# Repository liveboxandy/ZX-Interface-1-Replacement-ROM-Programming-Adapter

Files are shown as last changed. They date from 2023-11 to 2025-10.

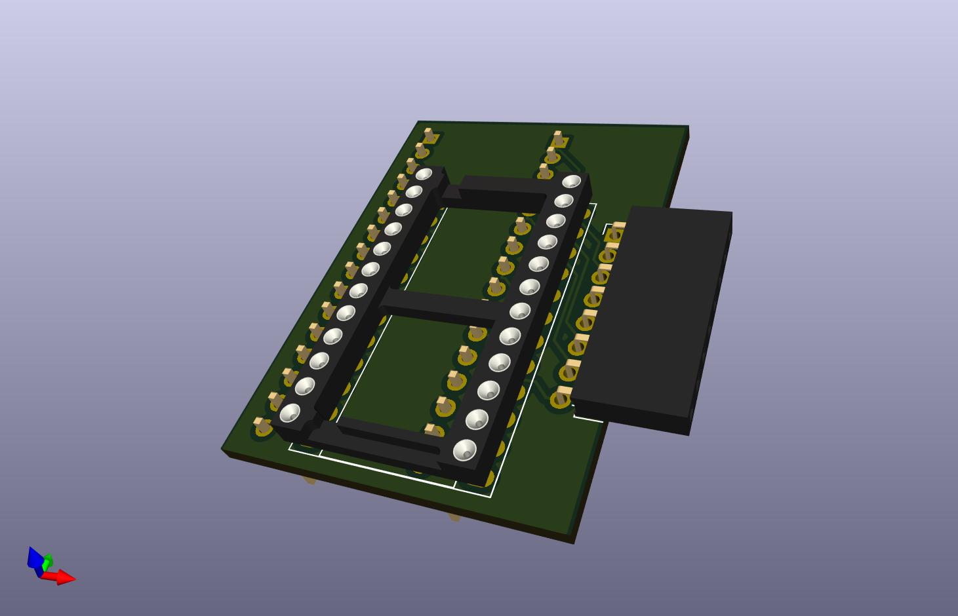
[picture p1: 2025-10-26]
ZX Interface 1 ROM Adapter.jpg

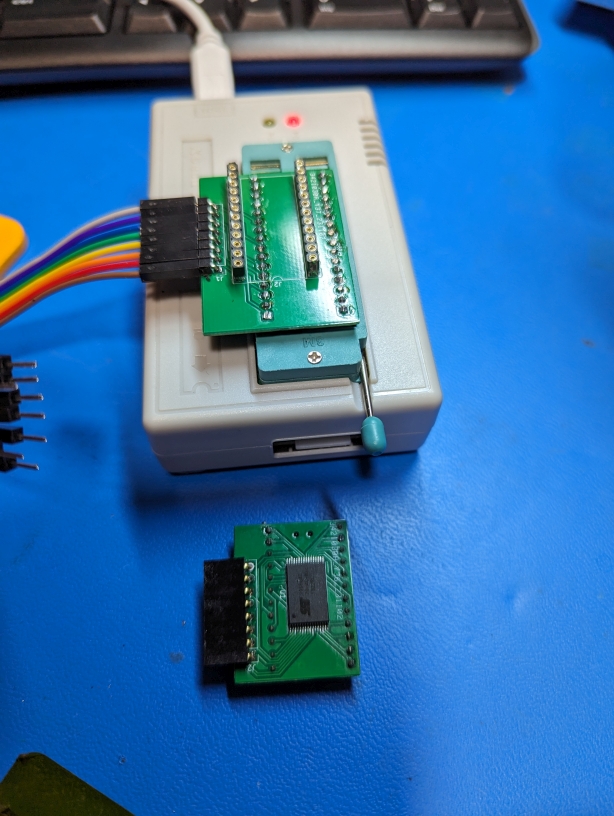
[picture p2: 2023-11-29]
Pictures/ROM Top.jpg

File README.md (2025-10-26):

# ZX-Interface-1-Replacement-ROM-Programming-Adapter
Programming adapter for the ZX Interface 1 Replacement ROM.

This is the programming adapter that is required to allow reprogramming of the ZX Interface 1 Replacement ROM.

You need to link J1 Pins 1-8 on the adapter PCB to J1 Pins 1-8 (1-1,2-2,3-3,4-4,5-5,6-6,7-7,8-8) on the ROM PCB and select the correct SST39SF device on the programmer. You do not need to connect the 9th pin on the replacement ROM. See the ROM folder for more information on layout of the ROM and where to place the ROM images.

It can also be used to reprogram the Retroleum 24-pin switchable ROM replacement module with a bit of faffing about. See the relevant picture in the pictures folder for connection details.

The Retroeleum ROM unused connector is wired as follows starting from the left pin.

A12, ~WE, A14, A13, ~CE

and is configured in the following manner,

A12 - connected to 24 Pin Socket Pin 21 and is left unconnected.

~WE pulled Hi by 10K resistor in normal operation. Can be overidden by programmer. Connect to Adapter J1 pin 1 to program.

A14 pulled Lo by 10K resistor in normal operation. Can be overidden by programmer. Connect to Adapter J1 Pin 6 to program.

A13 pulled Lo by 10K resistor in normal operation. Can be overidden by programmer. Connect to Adapter J1 Pin 7 to program. This can be used in the Interface 1 to allow the use of 16K ROM images. 

~CE pulled Lo by 10K resistor in normal operation. Can be overidden by programmer. Connect to Adapter J1 Pin 8 to program.

A15 selects ROM to use by the switch, pulls line Hi via 10K to 5V or Lo via short to Gnd. Can be manually switched when programming to allow different ROMs to be selected (8K images unless A13 will be connected in the IF1 when 16K images can be used).

A16 permanently connected to Ground. Cannot be overridden by programmer.

To program,

1 - Select the correct device SST39SF010 DIP32.

2 - Add wires for ~WE, A14, A13 and ~CE. See picture for details.

3 - Device ID 'should' work but programmer should complain with a Pin 2 connection error if Pin Detect is ON. Now turn OFF Pin Detect.

4 - Erase EEPROM.

5 - Set Switch to A.

6 - Load ROM A at offset 0x00000

7 - Program

8 - Set Switch to B.

9 - Load ROM B at offset 0x00000

10 - Program - Ensure that Erase before Programming is NOT selected.

You should now have two ROMs programmed and can be selected by the switch. 

If using 16K ROM images, connect A13 on the unused connector to address A13 on the Interface 1. This can be found on the Spectrum Edge Connector. See picture for details. 

Comments - Good Bad or indifferent on https://www.facebook.com/groups/zxspa/

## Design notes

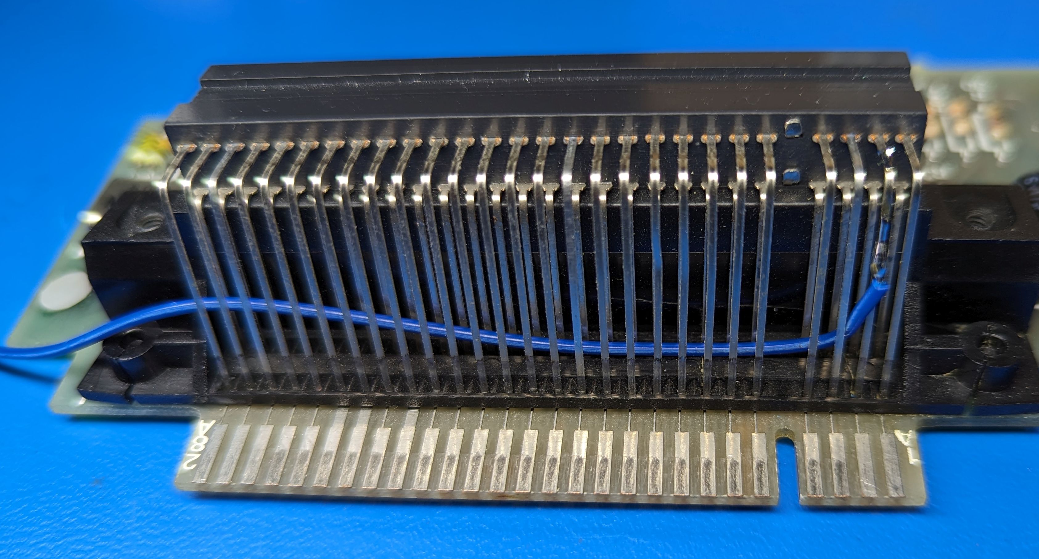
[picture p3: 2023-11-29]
Pictures/ZX Interface 1 A13 location.jpg

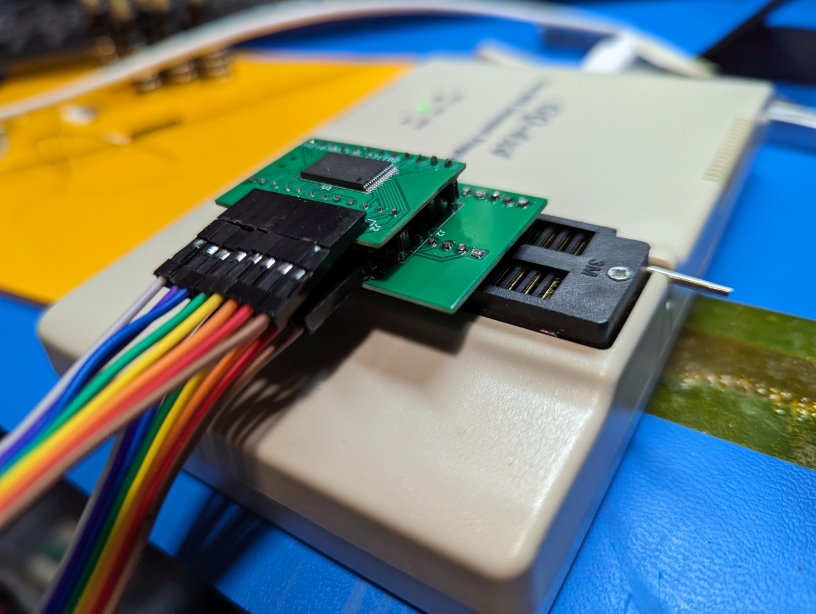
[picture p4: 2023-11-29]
Pictures/Programming 4x4.jpg

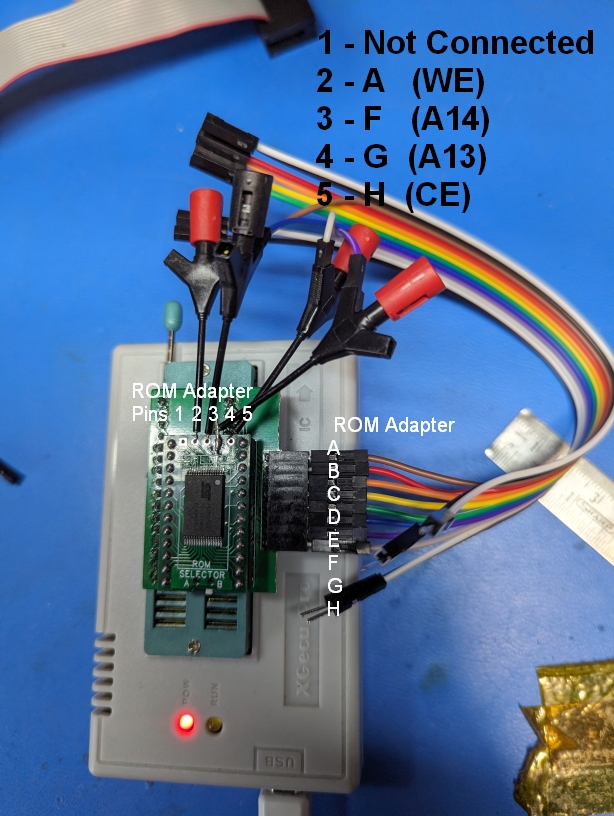
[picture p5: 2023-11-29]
Pictures/Retroleum ROM Connections.jpg

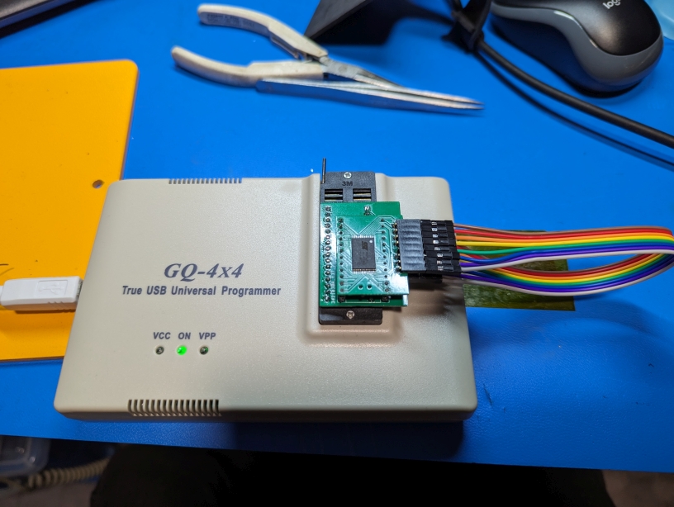
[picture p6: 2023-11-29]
Pictures/Programming 4x4 -1.jpg

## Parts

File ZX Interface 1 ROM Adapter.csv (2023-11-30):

Source: | W:\Emulators\Spectrum Repair\ZX Interface 1 ROM Adapter\ZX Interface 1 ROM Adapter.kicad_sch
Date: | 30/11/2023 16:16:49
Tool: | Eeschema 7.0.8
Generator: | C:\Program Files\KiCad\7.0\bin\scripting\plugins/bom_csv_grouped_by_value.py
Component Count: | 4
Collated Components:
Item | Qty | Reference(s) | Value | LibPart | Footprint | Datasheet | DNP | Height | Manufacturer_Name | Manufacturer_Part_Number | Mouser Part Number | Mouser Price/Stock
1 | 1 | J1 | Conn_01x08_Socket | Connector:Conn_01x08_Socket | Library:PinSocket_1x08_P2.54mm_HorizontalR | ~
2 | 1 | J2 | 24DIL Socket | DIL24:DILB24P-224TLF | Package_DIP:DIP-24_W15.24mm_Socket_LongPads | https://cdn.amphenol-cs.com/media/wysiwyg/files/drawing/10052485.pdf |  | 5.25 | Amphenol Communications Solutions | DILB24P-224TLF | 649-DILB24P-224TLF | https://www.mouser.co.uk/ProductDetail/Amphenol-FCI/DILB24P-224TLF?qs=cTNRJjk9LRekdjb2T7GbOg%3D%3D
3 | 2 | J3, J4 | Conn_01x16 | Connector_Generic:Conn_01x16 | Connector_PinHeader_2.54mm:PinHeader_1x16_P2.54mm_Vertical | ~

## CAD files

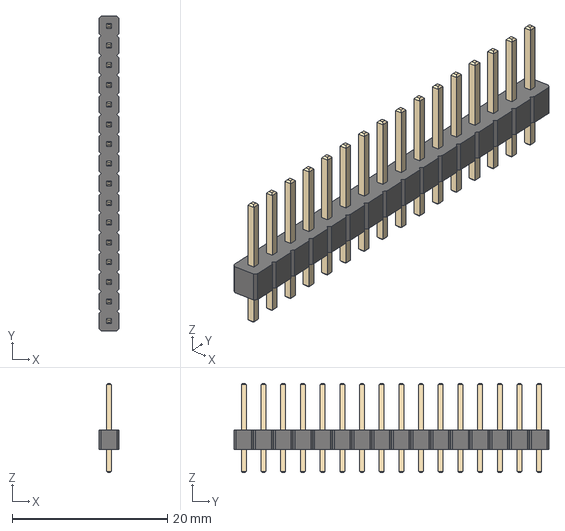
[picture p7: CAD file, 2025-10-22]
STEP/PinHeader_1x16_P2.54mm_Vertical.step
2.54 x 40.6 x 11.5 mm

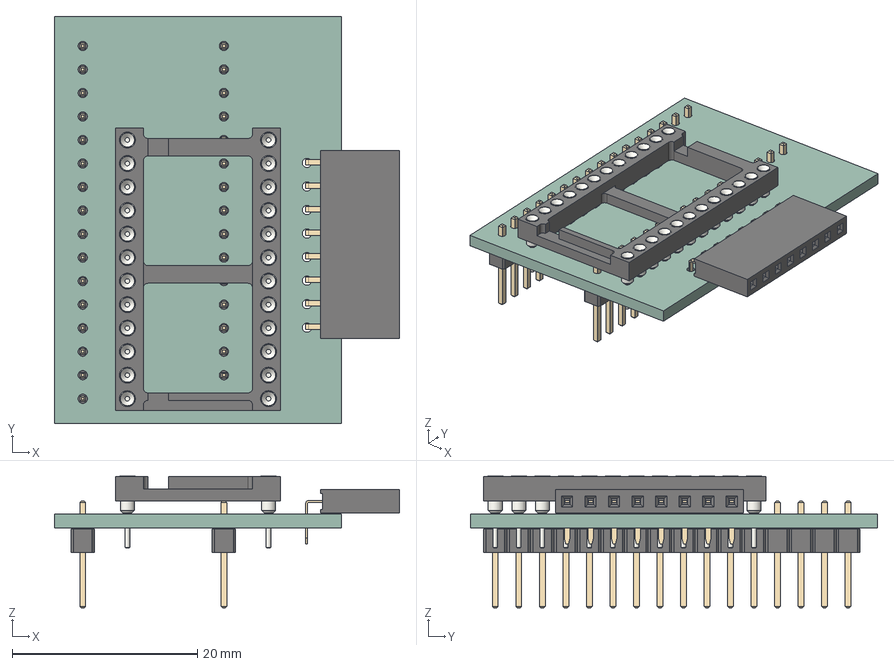
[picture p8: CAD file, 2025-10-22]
ZX Interface 1 ROM Adapter.step
37.3 x 44.0 x 14.2 mm
DIP-24_W15.24mm_Socket
PinSocket_1x08_P2.54mm_Horizontal
PinHeader_1x16_P2.54mm_Vertical x 2
ZX Interface 1 ROM Adapter_PCB

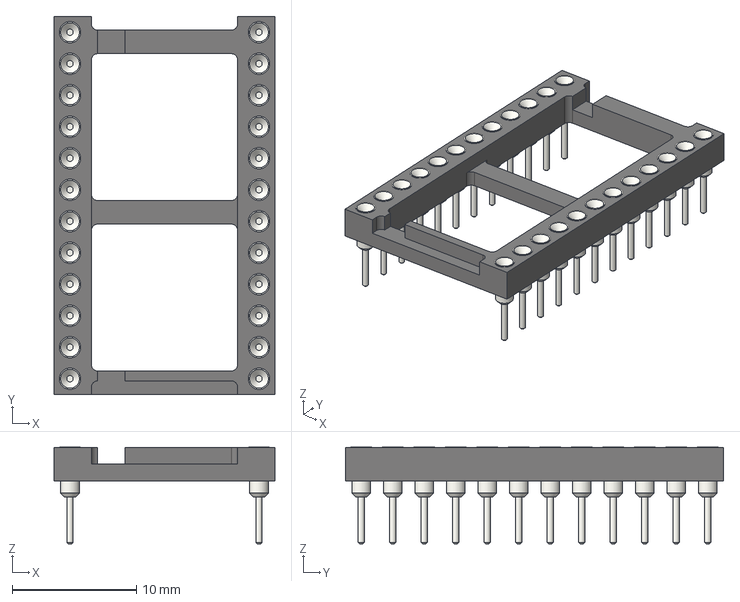
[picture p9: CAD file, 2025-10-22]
STEP/DIP-24_W15.24mm_Socket.step
17.8 x 30.5 x 7.79 mm

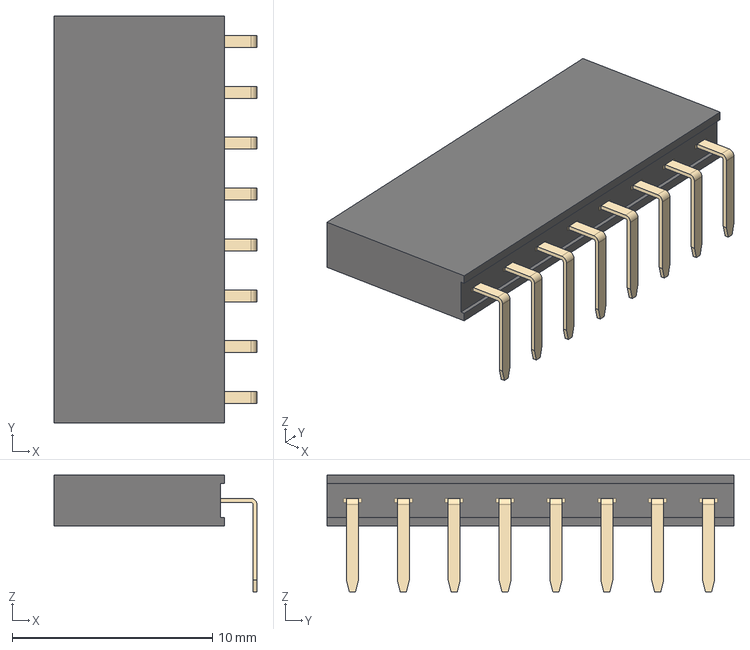
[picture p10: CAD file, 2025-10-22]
STEP/PinSocket_1x08_P2.54mm_Horizontal.step
10.1 x 20.3 x 5.84 mm

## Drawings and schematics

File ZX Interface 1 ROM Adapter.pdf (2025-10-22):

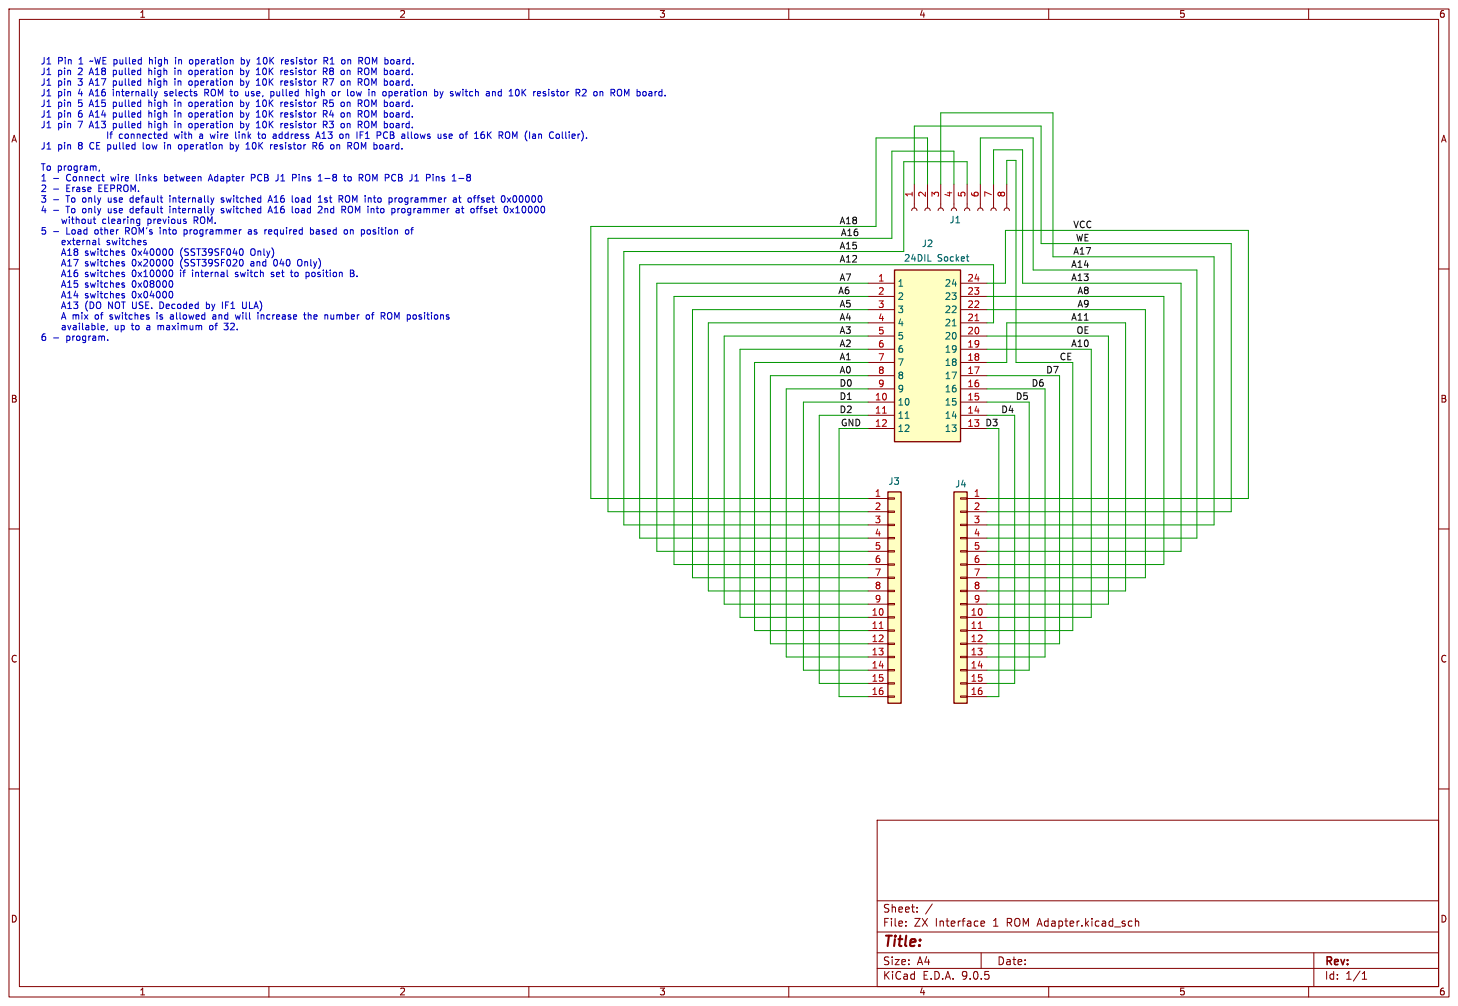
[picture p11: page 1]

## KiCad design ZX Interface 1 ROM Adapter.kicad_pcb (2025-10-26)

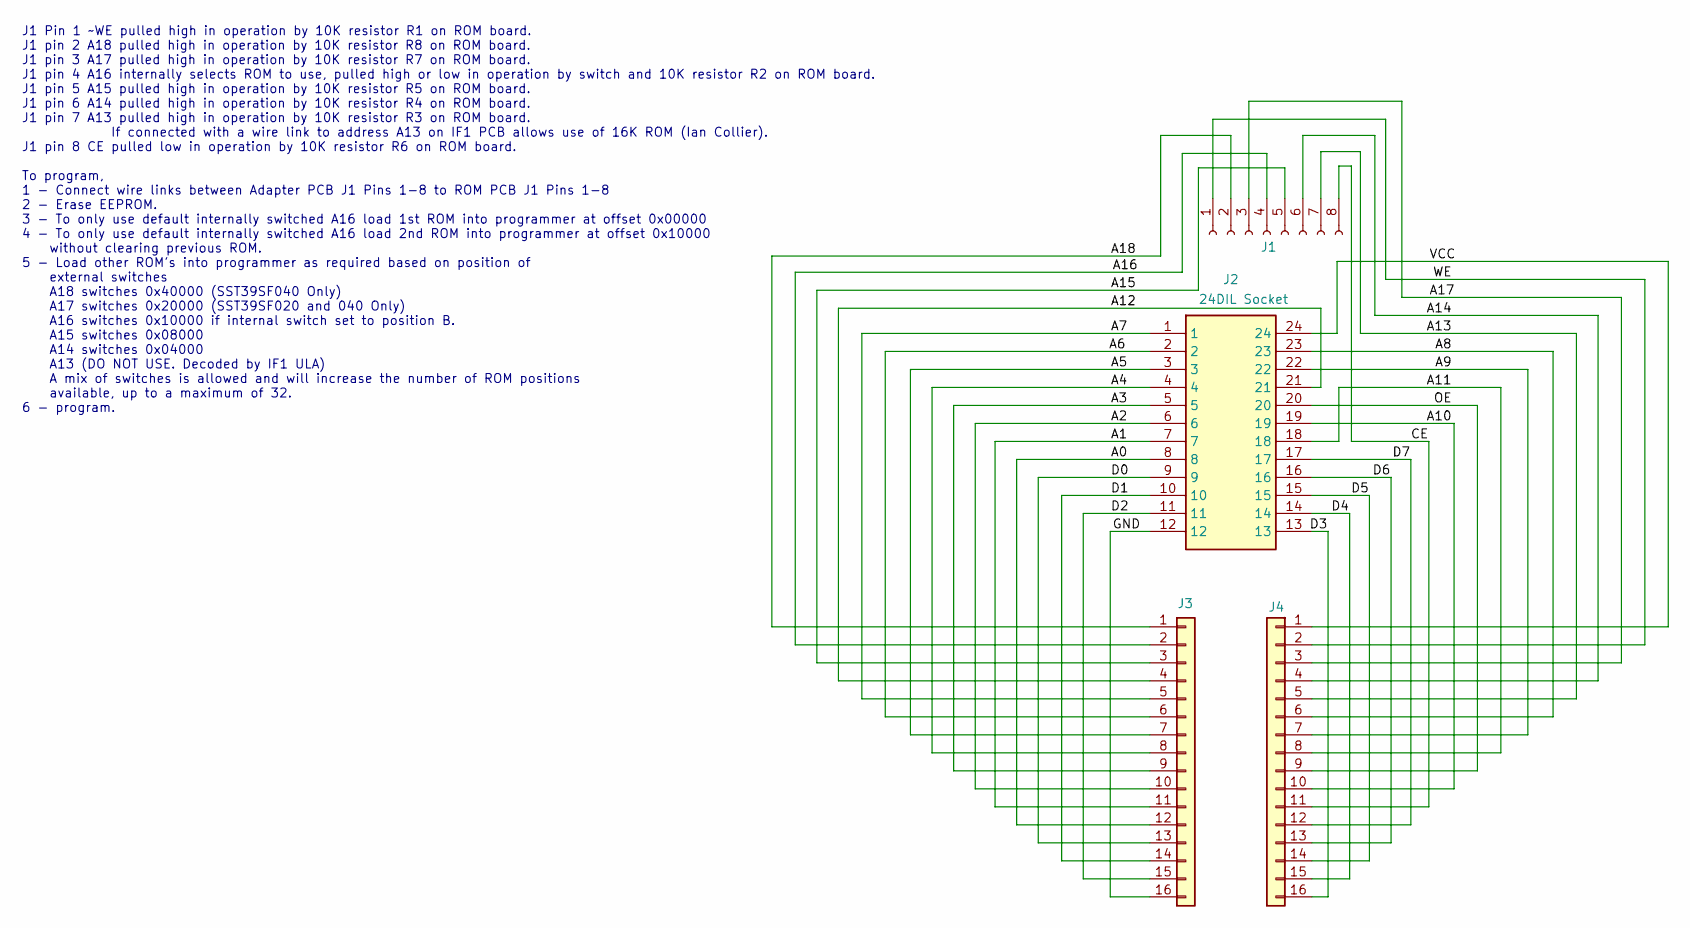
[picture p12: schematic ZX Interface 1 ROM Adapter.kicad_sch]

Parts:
J1: Conn_01x08_Socket; PinSocket_1x08_P2.54mm_HorizontalR
J2: 24DIL Socket; DIP-24_W15.24mm_Socket_LongPads; Mouser Part Number 649-DILB24P-224TLF
J3, J4: Conn_01x16; PinHeader_1x16_P2.54mm_Vertical

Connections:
/A0: J2.8, J3.12
/A1: J2.7, J3.11
/A2: J2.6, J3.10
/A3: J2.5, J3.9
/A4: J2.4, J3.8
/A5: J2.3, J3.7
/A6: J2.2, J3.6
/A7: J2.1, J3.5
/A8: J2.23, J4.6
/A9: J2.22, J4.7
/A10: J2.19, J4.10
/A11: J2.18, J4.8
/A12: J2.21, J3.4
/A13: J1.7, J4.5
/A14: J1.6, J4.4
/A15: J1.5, J3.3
/A16: J1.4, J3.2
/A17: J1.3, J4.3
/A18: J1.2, J3.1
/CE: J1.8, J4.11
/D0: J2.9, J3.13
/D1: J2.10, J3.14
/D2: J2.11, J3.15
/D3: J2.13, J4.16
/D4: J2.14, J4.15
/D5: J2.15, J4.14
/D6: J2.16, J4.13
/D7: J2.17, J4.12
/GND: J2.12, J3.16
/OE: J2.20, J4.9
/VCC: J2.24, J4.1
/WE: J1.1, J4.2

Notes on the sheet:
J1 Pin 1 ~WE pulled high in operation by 10K resistor R1 on ROM board. J1 pin 2 A18 pulled high in operation by 10K resistor R8 on ROM board. J1 pin 3 A17 pulled high in operation by 10K resistor R7 on ROM board. J1 pin 4 A16 internally selects ROM to use, pulled high or low in operation by switch 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

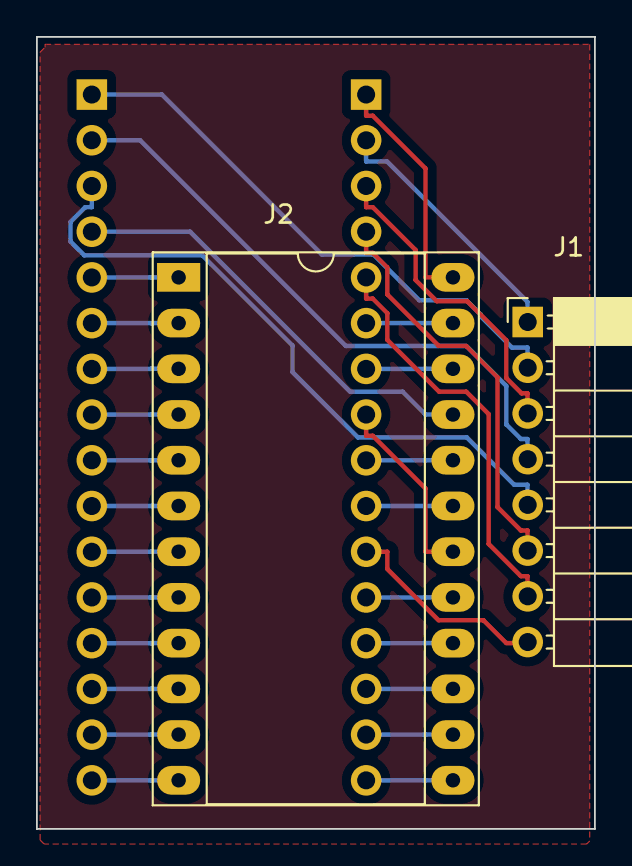
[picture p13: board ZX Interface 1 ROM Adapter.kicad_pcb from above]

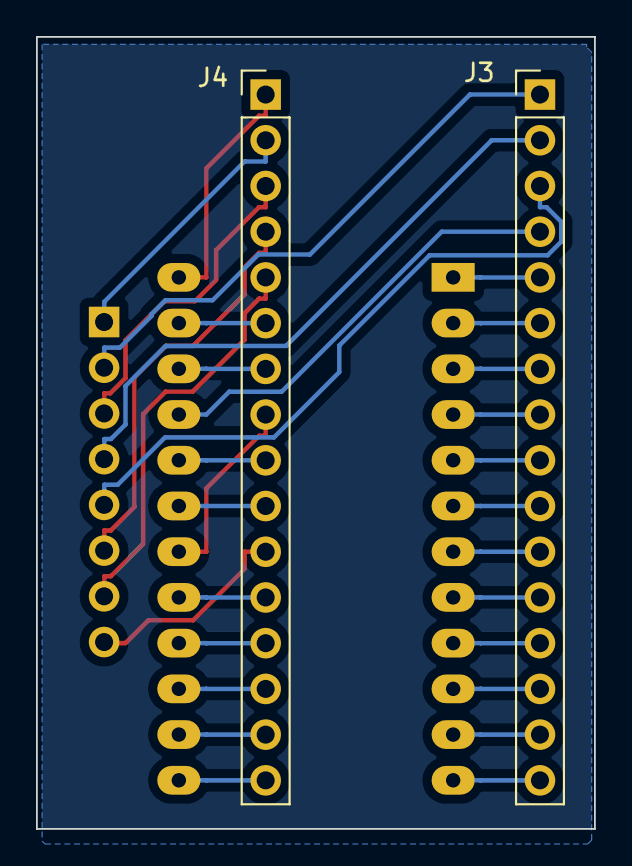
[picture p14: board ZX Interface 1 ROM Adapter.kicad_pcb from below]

Board: 2 copper layers, 31.0 x 44.0 mm, 4 parts (2 on the bottom side), 32 nets.

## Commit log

2023-11-30 Updated to use 8 Pin Right Angled Single-In-Line Connector
    [ZX Interface 1 ROM Adapter-B_Cu.gbl, ZX Interface 1 ROM Adapter-B_Mask.gbs, ZX Interface 1 ROM Adapter-B_Paste.gbp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]
2025-10-22 Add files via upload
    Updated to Kicad 9. Added ibom. Restructured folders.
    [DIP-24_W15.24mm_Socket.step, PinHeader_1x16_P2.54mm_Vertical.step, PinSocket_1x08_P2.54mm_Horizontal.step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]
2025-10-26 Update use of J1 Pins
    [ZX Interface 1 ROM Adapter.kicad_pcb]

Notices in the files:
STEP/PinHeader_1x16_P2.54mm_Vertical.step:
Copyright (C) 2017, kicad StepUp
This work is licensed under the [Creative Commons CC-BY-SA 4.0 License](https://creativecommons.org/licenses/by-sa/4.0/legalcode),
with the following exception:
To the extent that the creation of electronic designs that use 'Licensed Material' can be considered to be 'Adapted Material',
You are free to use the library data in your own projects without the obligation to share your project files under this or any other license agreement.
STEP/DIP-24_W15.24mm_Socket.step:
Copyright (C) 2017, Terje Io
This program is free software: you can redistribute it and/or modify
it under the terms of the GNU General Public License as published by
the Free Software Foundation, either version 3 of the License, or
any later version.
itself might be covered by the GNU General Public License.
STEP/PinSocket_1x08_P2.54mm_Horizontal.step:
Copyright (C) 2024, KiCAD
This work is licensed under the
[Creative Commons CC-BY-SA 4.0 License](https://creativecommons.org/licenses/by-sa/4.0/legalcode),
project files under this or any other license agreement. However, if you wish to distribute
